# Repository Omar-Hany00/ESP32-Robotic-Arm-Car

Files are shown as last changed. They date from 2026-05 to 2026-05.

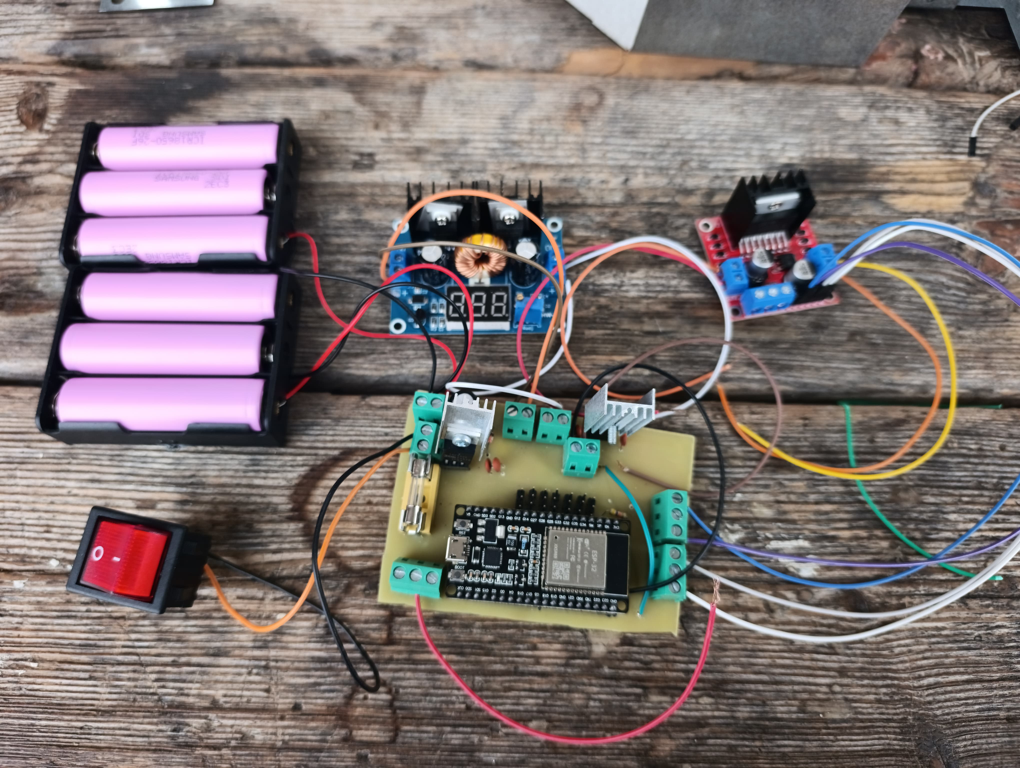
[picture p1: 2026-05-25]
final_assembly.jpg

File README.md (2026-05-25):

# ESP32 Robotic Arm Car

A custom ESP32-based robotic arm car designed for embedded control, wireless operation, and integrated PCB-based hardware management.

The project combines robotics, embedded systems, PCB design, and motor actuation into a compact mobile robotic platform featuring a servo-actuated robotic arm and custom-designed electronics.

---

## Features

- ESP32-based embedded control system
- Custom PCB designed using KiCad
- DC motor drive system
- Servo-controlled robotic arm
- Integrated power and signal routing
- Compact mobile robotic platform

---

## Hardware Overview

The system consists of:

- ESP32 microcontroller
- Custom-designed PCB
- DC drive motors
- Servo motors for robotic arm actuation
- Embedded power distribution circuitry

---

## Hardware Design

The PCB and schematic were designed using KiCad to integrate:
- ESP32 communication and control
- Motor driver connections
- Servo actuation outputs
- Power management and routing

---

## Tools Used

- KiCad
- ESP32
- Embedded C / Arduino Framework
- DC Motors
- Servo Motors

---

## Author

Omar Hany Mohammed

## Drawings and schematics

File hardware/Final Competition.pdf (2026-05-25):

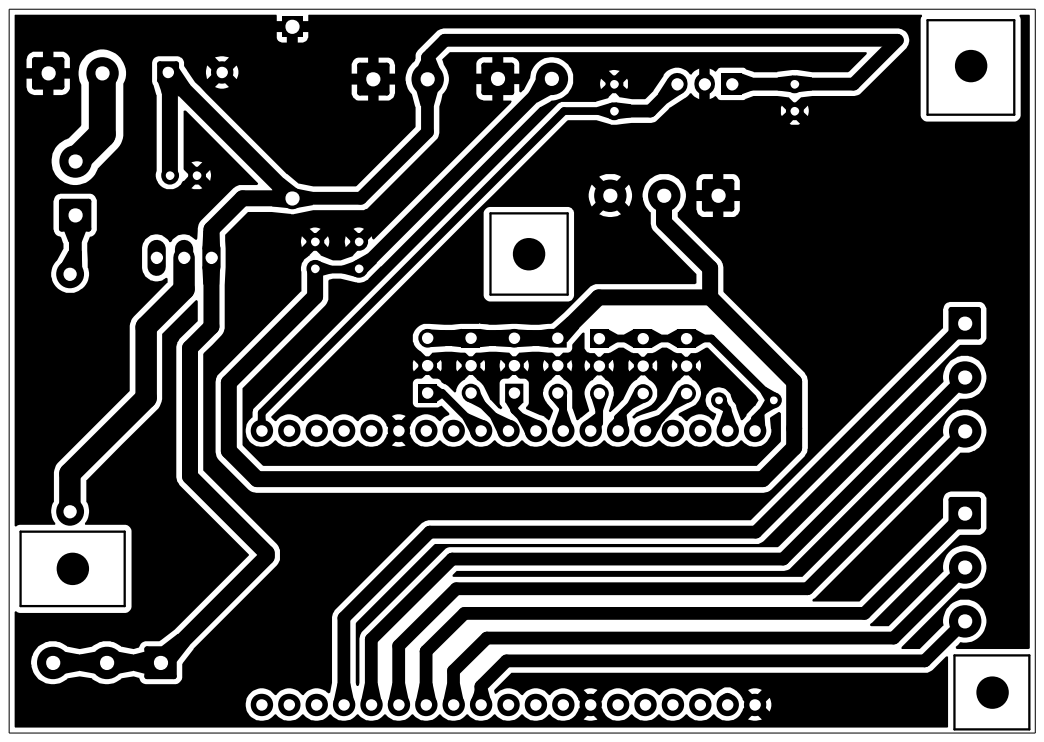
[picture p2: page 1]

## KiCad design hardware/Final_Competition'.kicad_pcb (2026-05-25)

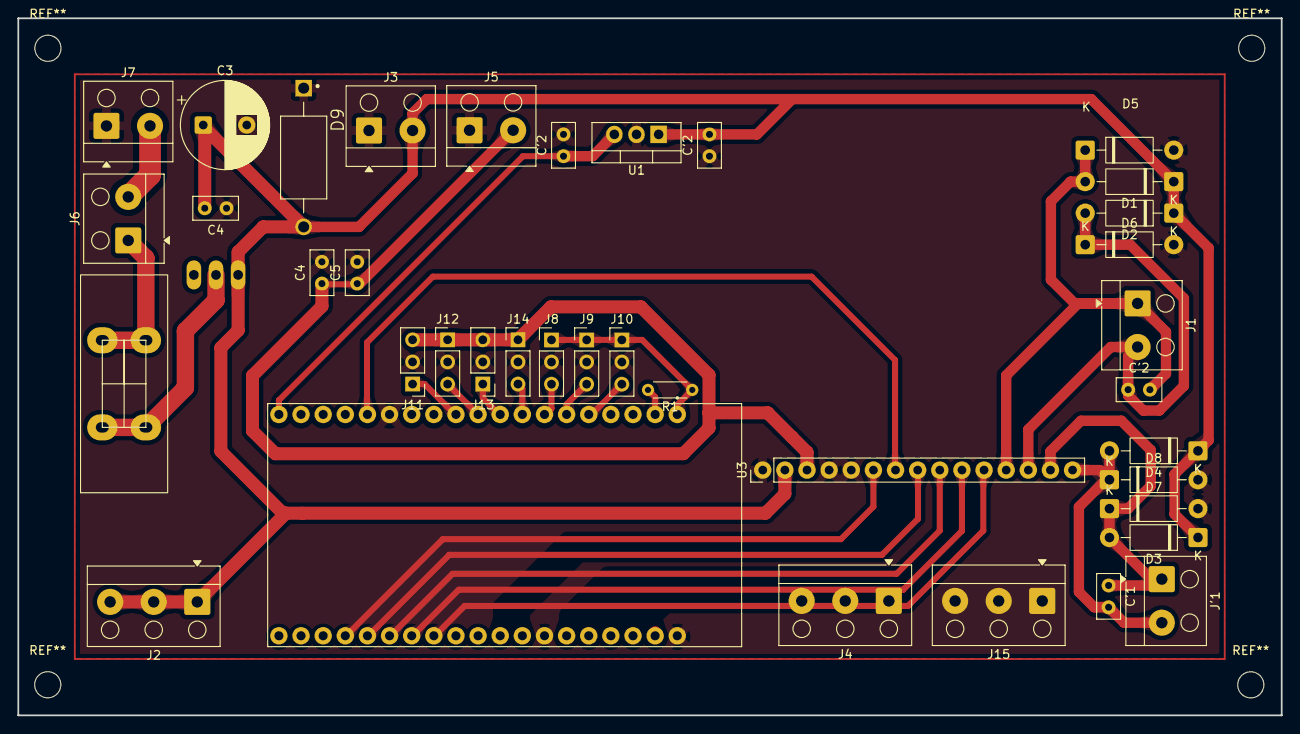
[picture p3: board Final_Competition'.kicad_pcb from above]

Board: 2 copper layers, 145.0 x 80.0 mm, 39 parts (0 on the bottom side), 25 nets.

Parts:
C3: 470uF; CP_Radial_D10.0mm_P5.00mm
C4: 1uF; C_Disc_D5.0mm_W2.5mm_P2.50mm
C4#2, C5: 100nF; C_Disc_D5.0mm_W2.5mm_P2.50mm
C'1, C'2, C'2#2, C'2#3: 100nF; C_Disc_D5.0mm_W2.5mm_P2.50mm
D1, D2, D3, D4, D5, D6, D7, D8: 1N4007; D_DO-41_SOD81_P10.16mm_Horizontal
D9: SMBJ18A; DIOAD1592W101L950D530
J1: Motor 1; Altech_AK100_1x02_P5.00mm
J2, J4, J15: Current Distribution; Altech_AK100_1x03_P5.00mm
J3: Buck Converter Input; Altech_AK100_1x02_P5.00mm
J5: Buck Converter Output; Altech_AK100_1x02_P5.00mm
J6: Switch; Altech_AK100_1x02_P5.00mm
J7: Battery Input; Altech_AK100_1x02_P5.00mm
J8: Sensor1; PinHeader_1x03_P2.54mm_Vertical
J9: Sensor2; PinHeader_1x03_P2.54mm_Vertical
J10: Sensor3; PinHeader_1x03_P2.54mm_Vertical
J11: Servo1; PinHeader_1x03_P2.54mm_Vertical
J12: Servo2; PinHeader_1x03_P2.54mm_Vertical
J13: Servo3; PinHeader_1x03_P2.54mm_Vertical
J14: Servo4; PinHeader_1x03_P2.54mm_Vertical
J'1: Motor 2; Altech_AK100_1x02_P5.00mm
Q1: IRF4905; TO220BH
R1: 10K; R_Axial_DIN0204_L3.6mm_D1.6mm_P5.08mm_Horizontal
TH1: MF-R600; Fuse_Holder_5x20
U1: L7805; TO-220-3_Vertical
U2: ESP32-DEVKITC-32D; MODULE_ESP32-DEVKITC-32D
U3: L298N; PinHeader_1x15_P2.54mm_Vertical

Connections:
3.3V: J8.1, J9.1, J10.1, R1.1, U2.J2-1 (3V3)
5V: C4.1, C5.1, J5.2, J11.3, J12.1, J13.3, J14.1, U3.3 (OUT2)
12V: C3.1, C4#2.2, C'2#2.2, D1.1 (K), D2.1 (K), D3.1 (K), D4.1 (K), J2.1, J2.2, J2.3, J3.2, U1.1 (IN), U3.2 (OUT1)
+12V: J6.2, J7.2
/Motor_Driver/OUT11: C'2#3.2, D1.2 (A), D5.1 (K), J1.1, U3.12 (IN4)
/Motor_Driver/OUT12: C'2#3.1, D2.2 (A), D6.1 (K), J1.2, U3.13 (OUT3)
/Motor_Driver/OUT21: C'1.1, D3.2 (A), D7.1 (K), J'1.1, U3.14 (OUT4)
/Motor_Driver/OUT22: C'1.2, D4.2 (A), D8.1 (K), J'1.2, U3.15 (SENSE_B)
/Power/Fuse: J6.1, TH1.2
EN1: J15.2, U2.J3-16 (IO15), U3.6 (ENA)
EN2: J4.2, U2.J2-15 (IO13), U3.7 (IN2)
GND: C3.2, C4.2, C4#2.1, C5.2, C'2.2, C'2#2.1, D5.2 (A), D6.2 (A), D7.2 (A), D8.2 (A), J3.1, J5.1, J7.1, J8.2, J9.2, J10.2, J11.2, J12.2, J13.2, J14.2, U1.2 (GND), U2.J2-14 (GND1), U2.J3-1 (GND3), U2.J3-7 (GND2), U3.1 (SENSE_A), U3.4 (VS), U3.5 (IN1)
IN11: J15.3, U2.J3-15 (IO2), U3.8 (GND)
IN12: J15.1, U2.J3-14 (IO0), U3.9 (VSS)
IN21: J4.1, U2.J3-13 (IO4), U3.10 (IN3)
IN22: J4.3, U2.J3-12 (IO16), U3.11 (ENB)
IR1: J8.3, U2.J2-7 (IO32)
IR2: J9.3, U2.J2-6 (IO35)
IR3: J10.3, U2.J2-5 (IO34)
unnamed: C'2.1, U1.3 (OUT), U2.J2-19 (EXT_5V)
unnamed: R1.2, U2.J2-2 (EN)
Servo1: J11.1, U2.J2-11 (IO27)
Servo2: J12.3, U2.J2-10 (IO26)
Servo3: J13.1, U2.J2-9 (IO25)
Servo4: J14.3, U2.J2-8 (IO33)
